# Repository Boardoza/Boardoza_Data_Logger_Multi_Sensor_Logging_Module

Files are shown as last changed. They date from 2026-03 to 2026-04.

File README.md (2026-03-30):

# Boardoza Data Logger Multi Sensor Logging Module

The **Boardoza Data Logger** is a powerful and compact data acquisition module designed for robust environmental, positional, and motion data logging. Built around the **ESP32-S module**, it combines high-performance on-board processing with wireless connectivity, making it ideal for both standalone and connected data logging applications.

By integrating multiple advanced sensors—including a 9-axis IMU, high-resolution barometric pressure sensor, and a precision GPS module—this board provides a complete solution for recording motion, altitude, orientation, and location data. With support for MicroSD storage and a wide input voltage range, the Boardoza Data Logger is well-suited for long-duration deployments in demanding environments such as aerospace experiments, environmental monitoring, robotics, and mobile data recording systems.

## [Click here to purchase!](https://www.ozdisan.com/p/arduino-sensorleri-ve-modulleri-613/boardoza-data-logger-1473935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)

| Front Side | Back Side |
|:---:|:---:|
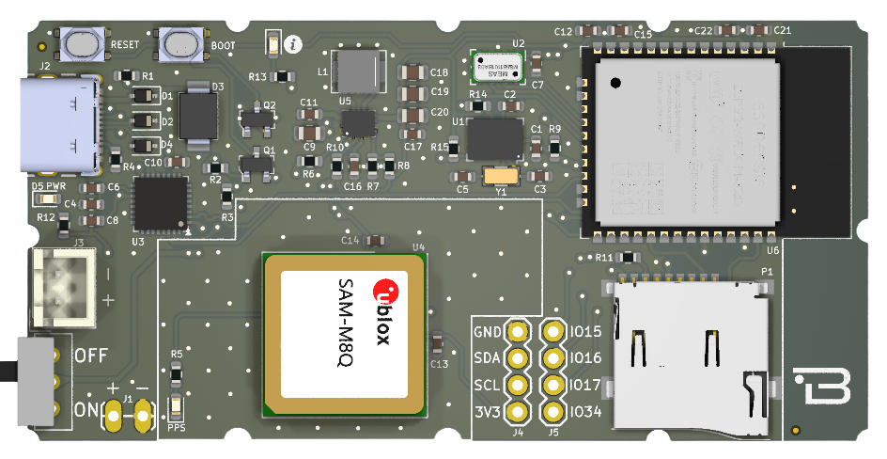
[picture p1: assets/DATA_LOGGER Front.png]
Data Logger Front
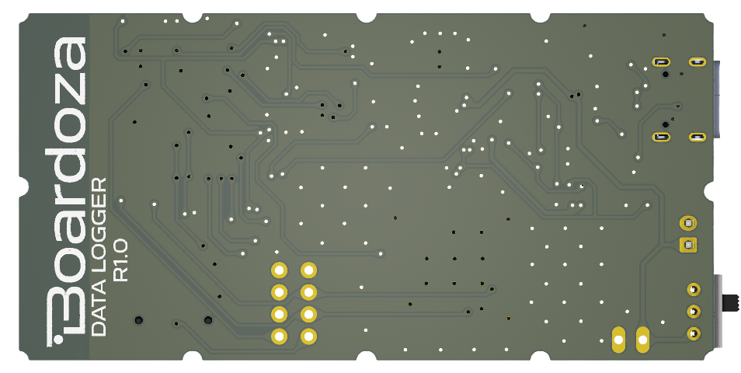
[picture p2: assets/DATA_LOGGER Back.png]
Data Logger Back
|  |  |

---

## Key Features

- **ESP32-S Module MCU:** Dual-core microcontroller with integrated Wi-Fi and Bluetooth for wireless data transmission.
- **Integrated 9-Axis IMU:** Combines accelerometer, gyroscope, and magnetometer for accurate motion and orientation tracking.
- **High-Resolution Barometric Sensor:** Enables precise pressure and altitude measurements.
- **Onboard GPS Module:** Provides reliable global positioning, speed, and navigation data.
- **MicroSD Card Support:** Allows long-term local data logging without external connectivity.
- **Wide Input Voltage Range:** Supports flexible power sources through an onboard buck-boost regulator.
- **External Expansion Pins:** Accessible I²C and GPIO pins for additional sensors and peripherals.
- **Designed for Harsh Environments:** Suitable for mobile, outdoor, and experimental applications.

---

## Technical Specifications

**Model:** Data Logger  
**Manufacturer:** Boardoza  
**MCU:** ESP32-S Module  
**Wireless Connectivity:** Wi-Fi (802.11 b/g/n/d/e/i/k/r), Bluetooth v4.2 BR/EDR and BLE    
**IMU Sensor:** BNO055 (9-axis: accelerometer, gyroscope, magnetometer, temperature)  
**Pressure and Temperature Sensor:** MS5611-01BA03  
**GPS Module:** u-blox SAM-M8Q  
**Input Voltage:** 3 V – 16 V  
**Voltage Regulation:** Onboard buck-boost regulator  
**Data Storage:** MicroSD Card  
**External Interfaces:** I²C, GPIO  
**Measured Data:** Acceleration, angular velocity, magnetic field, pressure, altitude, temperature, location, speed, timestamp     
**Operating Temperature:** -40 °C to +85 °C  
**Board Dimensions:** 40 mm × 80 mm

---

## Board Pinout

### **( J1 ) Power Connector**

| Pin Number | Pin Name | Description |
| --- | --- | --- |
| 1 | + | Power Input |
| 2 | - | Ground |

### **( J2 ) Power Connector**

| Pin Number | Pin Name | Description |
| --- | --- | --- |
| 1 | + | Power Input |
| 2 | - | Ground |

### **( J4 ) I²C Connector**

| Pin Number | Pin Name | Description |
| --- | --- | --- |
| 1 | 3V3 | 3.3V Output |
| 2 | SCL | I²C Serial Clock |
| 3 | SDA | I²C Serial Data |
| 4 | GND | Ground |

### **( J5 ) GPIO Connector**

| Pin Number | Pin Name | Description |
| --- | --- | --- |
| 1 | IO34 | ESP32 GPIO34 |
| 2 | IO17 | ESP32 GPIO17 |
| 3 | IO16 | ESP32 GPIO16 |
| 4 | IO15 | ESP32 GPIO15 |

---

## Sample Flight Data

Example altitude profile recorded during an amateur rocket flight:

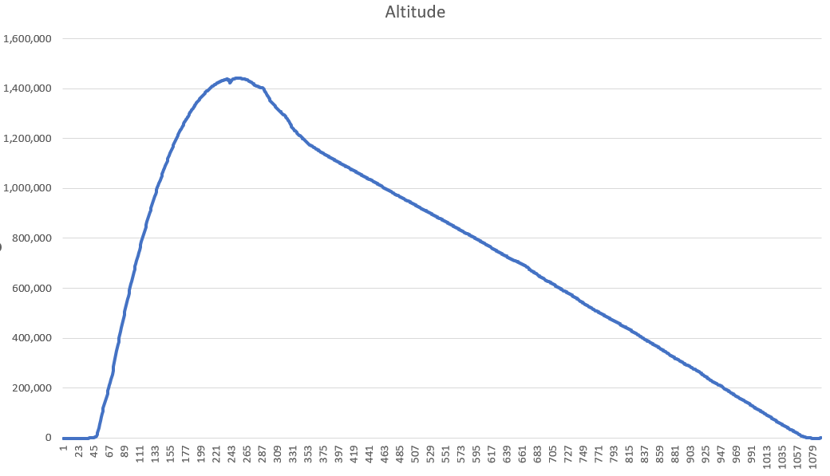
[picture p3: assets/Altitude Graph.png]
Altitude Graph


- Maximum altitude ~1,440 meters  
- Smooth ascent profile followed by controlled descent  
- Data logged using onboard MicroSD  

**Raw data file:**  
[Flight1.csv](./assets/_Flight1.csv)

**Simulation video:**  
[Data Logger Simulation.mp4](./assets/Data%20Logger%20Simulation.mp4)

---

## Board Dimensions

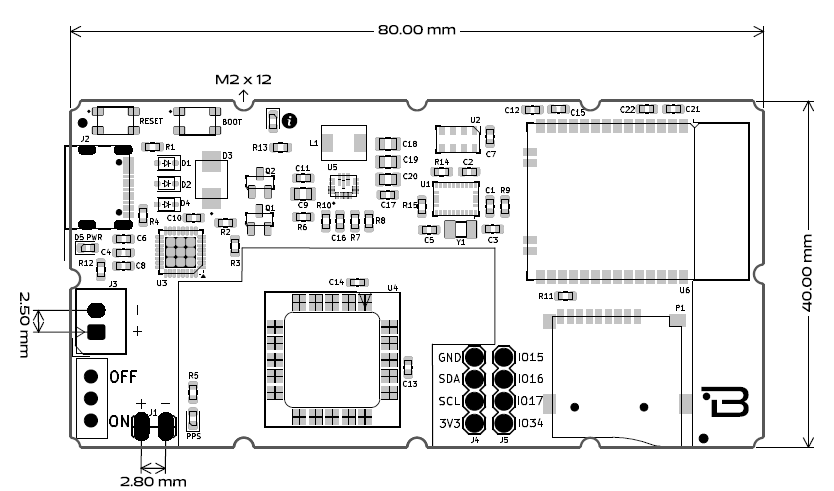
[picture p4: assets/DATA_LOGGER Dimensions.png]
Board Dimensions


---

## Step Files

[Boardoza Data Logger.step](./assets/DATA_LOGGER%20Step.step)

---

## Datasheets

- [BNO055 Datasheet](./assets/BNO055%20Datasheet.pdf)   
- [MS5611-01BA03 Datasheet](./assets/MS5611-01BA03%20Datasheet.pdf)  
- [SAM-M8Q Datasheet](./assets/SAM_M8Q%20Datasheet.pdf)  
- [TPS63070 Datasheet](./assets/TPS63070%20Datasheet.pdf)    

---

## Version History

- V1.0.0 – Initial Release

---

## Support

- If you have any questions or need support, please contact **support@boardoza.com**

---

## **License**

This repository contains both hardware and software components:

### **Hardware Design**

[][cc-by-sa]

All hardware design files are licensed under [Creative Commons Attribution-ShareAlike 4.0 International License][cc-by-sa].

[cc-by-sa]: http://creativecommons.org/licenses/by-sa/4.0/
[cc-by-sa-shield]: https://img.shields.io/badge/License-CC%20BY--SA%204.0-lightgrey.svg

### **Software/Firmware**

[][bsd]

All software and firmware are licensed under [BSD 3-Clause License][bsd].

[bsd]: https://opensource.org/licenses/BSD-3-Clause
[bsd-shield]: https://img.shields.io/badge/License-BSD%203--Clause-blue.svg

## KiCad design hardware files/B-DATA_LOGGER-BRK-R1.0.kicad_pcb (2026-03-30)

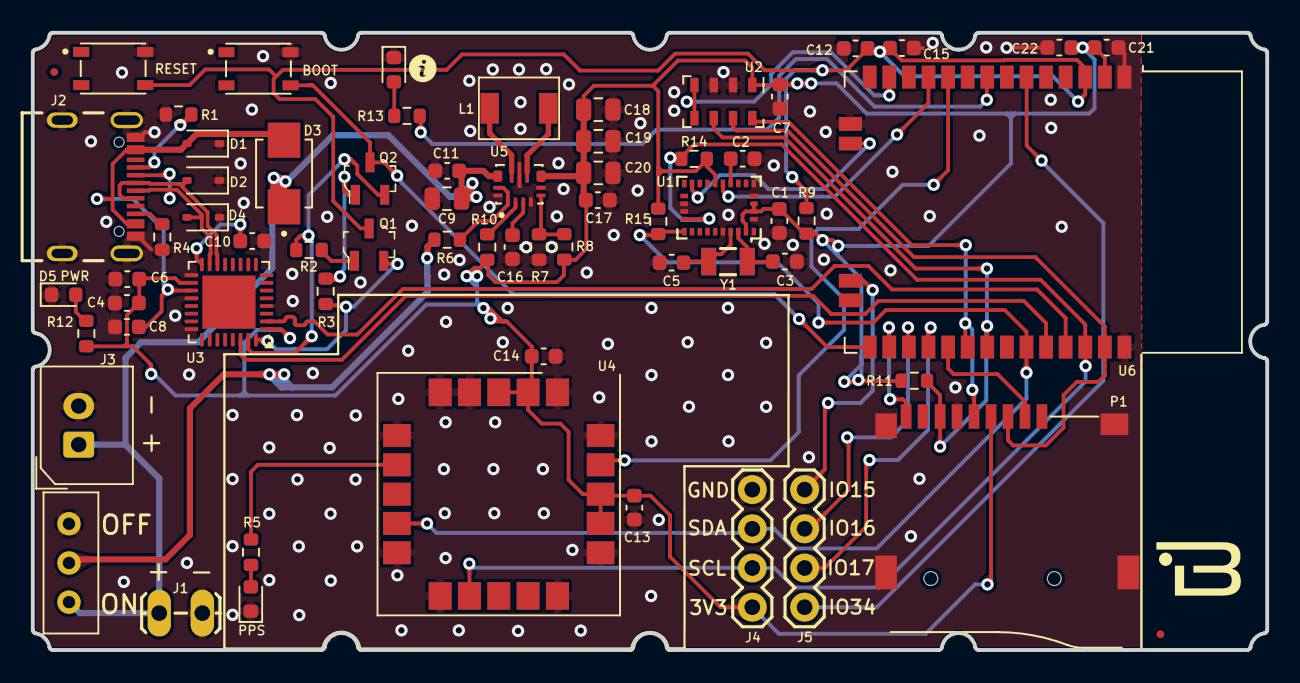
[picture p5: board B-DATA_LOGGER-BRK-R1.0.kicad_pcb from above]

Board: 2 copper layers, 80.0 x 40.0 mm, 63 parts (0 on the bottom side), 47 nets.

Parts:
BOOT1: PTS810_SJM_250_SMTR_LFS; SW_PTS810_SJM_250_SMTR_LFS
C1, C4, C6, C7, C8, C12, C13, C14, C15, C16, C22: 100nF; C_0603_1608Metric
C2, C10: 1uF; C_0603_1608Metric
C3, C5: 22pF; C_0603_1608Metric
C9, C18, C19, C20: 22uF; C_0805_2012Metric
C11, C17: 10uF; C_0603_1608Metric
C21: 22uF; C_0603_1608Metric
D1, D2, D4: SD05_SOD323; D_SOD-323
D3: SS24; DIOM5336X265N
D5: LED POWER RED; LED_0603_1608Metric
D6: LED BLUE; LED_0603_1608Metric
J1: Power pin; 1X02_LOCK_LONGPADS
J2: USB4105-GF-A; GCT_USB4105-GF-A
J3: 2317-02; 2317-02S_1x02_P2.50mm_Vertical
J4, J5: CONN_04; 1X04
L1: SMPI04020-1R5M; SMPI04020
P1: L-KLS1-TF-003-H1.85-R; SUNTECH_ST-TF-003A
PPS: LED GREEN; LED_0603_1608Metric
Q1, Q2: S8050; SOT-23-3
R1, R4: 5.1K; R_0603_1608Metric
R2, R3, R6, R9, R11, R14, R15: 10K; R_0603_1608Metric
R5, R12, R13: 1K; R_0603_1608Metric
R7: 150K; R_0603_1608Metric
R8: 470K; R_0603_1608Metric
R10: 100K; R_0603_1608Metric
RESET1: PTS810_SJM_250_SMTR_LFS; SW_PTS810_SJM_250_SMTR_LFS
S1: switch; K3-1260D
U1: BNO055; LGA-28_5.2x3.8mm_BNO0055
U2: MS5611-01BA; LGA-8_3x5mm_P1.25mm
U3: CY7C65213A-32LTXI; QFN-32-1EP_5x5mm_P0.5mm_EP3.45x3.45mm
U4: ublox_SAM-M8Q
U5: TPS630702RNMR; TPS63070RNMT
U6: ESP32-S; ESP32-WROOM-32D
Y1: CRYSTAL-32.768KHZSMD-3.2X1.5; CRYSTAL-SMD-3.2X1.5MM

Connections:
+3V3: C1.1, C4.1, C6.1, C7.1, C13.1, C14.1, C17.1, C18.1, C19.1, C20.1, C21.1, C22.1, J4.1, P1.4 (VDD), R8.2, R9.2, R10.1, R11.1, R12.1, R14.2, R15.2, U1.3 (VDD), U1.4 (BOOT_LOAD), U1.11 (RESET), U1.28 (VDDIO), U2.1 (VDD), U3.1 (VCCIO), U3.18 (~RESET), U4.2 (VCC_IO), U4.3 (V_BCKP), U4.17 (VCC), U4.18 (~RESET), U5.7_8 (VOUT), U6.2 (VDD)
+5V: C8.1, D1.2 (A2), D3.A, J2.A4_B9 (VBUS), J2.B4_A9 (VBUS), U3.19 (VCC)
+5VA: C9.1, C11.1, D3.C, J1.1, J3.1 (Pin_2), S1.3 (S), U5.12_13 (VIN)
BL_IND: U1.10 (BL_IND), U6.11 (IO26)
BNO_INT: U1.14 (INT), U6.16 (IO13)
D+: D2.2 (A2), J2.A6 (DP1), J2.B6 (DP2), U3.14 (USBDP)
D-: D4.2 (A2), J2.A7 (DN1), J2.B7 (DN2), U3.15 (USBDM)
DTR: Q2.2 (E), R2.2, U3.31 (DTR)
EN: C12.2, C15.1, Q1.3 (C), R9.1, RESET1.4, U6.3 (EN)
GND: BOOT1.2, C1.2, C2.2, C3.1, C4.2, C5.1, C6.2, C7.2, C8.2, C9.2, C10.2, C11.2, C12.1, C13.2, C14.2, C15.2, C16.2, C17.2, C18.2, C19.2, C20.2, C21.2, C22.2, D1.1 (A1), D2.1 (A1), D4.1 (A1), D5.1 (K), D6.1 (K), J1.2, J2.A1_B12 (GND), J2.B1_A12 (GND), J2.S1 (SHELL_GND), J2.S2 (SHELL_GND), J2.S3 (SHELL_GND), J2.S4 (SHELL_GND), J3.2 (Pin_1), J4.4, P1.6 (VSS), P1.G1 (GND), P1.G2 (GND), P1.G3 (GND), P1.G4 (GND), PPS.1 (K), R1.1, R4.1, R7.1, RESET1.2, S1.1 (O), U1.2 (GND), U1.5 (PS1), U1.6 (PS0), U1.17 (COM3), U1.18 (COM2), U1.25 (GNDIO), U2.2 (PS), U2.3 (GND), U3.4 (GND), U3.17 (GND), U3.20 (GND), U3.24 (AGND), U4.1 (GND), U4.4 (GND), U4.5 (GND), U4.6 (GND), U4.10 (GND), U4.11 (GND), U4.15 (GND), U4.16 (GND), U4.20 (GND), U5.4 (GND), U5.6 (FB2), U5.10 (PGND), U5.15 (VSEL), U6.1 (GND), U6.15 (GND), U6.38 (GND)
GPS_INT: U4.19 (EXTINT), U6.10 (IO25)
IO0: BOOT1.4, Q2.3 (C), U6.25 (IO0)
IO15: J5.1, U6.23 (IO15)
IO16: J5.2, U6.27 (IO16)
IO17: J5.3, U6.28 (IO17)
IO34: J5.4, U6.6 (IO34)
LED_INFO: R13.1, U6.8 (IO32)
MISO: P1.7 (DAT0), R11.2, U2.6 (SDO), U6.31 (IO19)
MOSI: P1.3 (CMD), U2.7 (SDI/SDA), U6.37 (IO23)
MS5611_CS: U2.4 (CSB), U2.5 (CSB), U6.13 (IO14)
unnamed: D5.2 (A), R12.2
unnamed: D6.2 (A), R13.2
unnamed: J2.A5 (CC1), R1.2
unnamed: J2.B5 (CC2), R4.2
unnamed: PPS.2 (A), R5.2
unnamed: Q1.1 (B), R2.1
unnamed: Q2.1 (B), R3.1
unnamed: R6.1, S1.2
unnamed: C2.1, U1.9 (CAP)
unnamed: C3.2, U1.27 (XIN32), Y1.P$1 (1)
unnamed: C5.2, U1.26 (XOUT32), Y1.P$2 (2)
unnamed: C10.1, U3.16 (VCCD)
unnamed: R5.1, U4.7 (TIMEPULSE)
unnamed: R6.2, U5.1 (PS/SYNC), U5.14 (EN)
unnamed: R7.2, R8.1, U5.5 (FB)
unnamed: L1.2, U5.11 (L1)
unnamed: L1.1, U5.9 (L2)
unnamed: R10.2, U5.2 (PG)
unnamed: C16.1, U5.3 (VAUX)
RTS: Q1.2 (E), R3.2, U3.32 (RTS)
RXD: U3.2 (RXD), U6.35 (TXD0/IO1)
SCK: P1.5 (CLK), U2.8 (SCLK), U6.30 (IO18)
SCL: J4.2, R14.1, U1.19 (COM1), U4.12 (SCL), U6.36 (IO22)
SDA: J4.3, R15.1, U1.20 (COM0), U4.9 (SDA), U6.33 (IO21)
SD_CS: P1.2 (DAT3), U6.29 (IO5)
SD_INSERT: P1.9 (CD), U6.26 (IO4)
TXD: U3.30 (TXD), U6.34 (RXD0/IO3)

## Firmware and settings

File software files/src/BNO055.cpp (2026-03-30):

#include "BNO055.h"
#include <SoftwareSerial.h>

SoftwareSerial mySerial(21, 22);

#define I2C
//#define UART

/**
 * @brief Constructor for BNO055 class.
 * 
 * Initializes the BNO055 object with the sensor's I2C address.
 * 
 */
BNO055::BNO055() {
    address = 0x28; // BNO055 sensor's I2C address
}

/**
 * @brief Initializes the BNO055 sensor.
 * 
 * This function initializes the BNO055 sensor by setting the necessary configurations and modes.
 * 
 * @return True if the sensor is successfully initialized, false otherwise.
 */
bool BNO055::begin() {
    #ifdef I2C
    Wire.begin();
    setPage(0x00);
    writeByte(0x3D, 0x00);
    delay(50);
    setPowerMode(PowerMode::POWERMODE_NORMAL);
    delay(10);
    setOperationMode(OperationMode::OPERATION_MODE_CONFIG);
    delay(50);
    return isReady();
    #endif

    #ifdef UART
    mySerial.begin(115200);
    setPage(0x00);
    writeByte(0x3D, 0x00);
    delay(30);
    setPowerMode(PowerMode::POWERMODE_NORMAL);
    delay(20);
    setOperationMode(OperationMode::OPERATION_MODE_CONFIG);
    delay(30);
    return isReady();
    #endif
}

/**
 * @brief Resets the BNO055 sensor.
 * 
 * This function performs a reset on the BNO055 sensor by triggering a reset sequence.
 * 
 */
void BNO055::reset() {
    setPage(0x00);
    writeByte(SYS_TRIGGER, 0x20);    
    delay(500);
    writeByte(SYS_TRIGGER, 0x00);
    delay(50);
}

/**
 * @brief Checks if the BNO055 sensor is ready.
 * 
 * This function checks the self-test result register to determine if the sensor is ready for operation.
 * 
 * @return True if the sensor is ready, false otherwise.
 */
bool BNO055::isReady() {
    setPage(0x00);
    uint8_t selfTest = readByte(SELFTEST_RESULT);

    return (selfTest & 0x0F);
}

/**
 * @brief Sets the power mode of the BNO055 sensor.
 * 
 * This function sets the power mode of the BNO055 sensor to the specified mode.
 * 
 * @param powermode The power mode to set (NORMAL, LOWPOWER, SUSPEND).
 */
void BNO055::setPowerMode(PowerMode powermode) {
    setPage(0x00);
    writeByte(PWR_MODE, powermode);
}

/**
 * @brief Sets the operation mode of the BNO055 sensor.
 * 
 * This function sets the operation mode of the BNO055 sensor to the specified mode.
 * 
 * @param mode The operation mode to set (CONFIG, ACCONLY, MAGONLY, GYRONLY, etc.).
 */
void BNO055::setOperationMode(OperationMode mode) {
    setPage(0x00);
    writeByte(OPR_MODE, mode);
}

/**
 * @brief Gets the current operation mode of the BNO055 sensor.
 * 
 * This function reads the operation mode register of the BNO055 sensor to get the current operation mode.
 * 
 * @return The current operation mode of the sensor (CONFIG, ACCONLY, MAGONLY, GYRONLY, etc.).
 */
OperationMode BNO055::getMode() {
    setPage(0x00);
    return (OperationMode)readByte(OPR_MODE);
}

/**
 * @brief Sets the page ID of the BNO055 sensor.
 * 
 * This function sets the page ID of the BNO055 sensor to the specified page.
 * 
 * @param page The page ID to set.
 */
void BNO055::setPage(uint8_t page) {
    writeByte(PAGE_ID, page);
}

/**
 * @brief Gets the current page ID of the BNO055 sensor.
 * 
 * This function reads the page ID register of the BNO055 sensor to get the current page ID.
 * 
 * @return The current page ID of the sensor.
 */
void BNO055::getPage() {
    readByte(PAGE_ID);
}

/**
 * @brief Resets the interrupt of the BNO055 sensor.
 * 
 * This function resets the interrupt of the BNO055 sensor by writing a specific value to the SYS_TRIGGER register. 
 */
void BNO055::interruptReset() {
    writeByte(SYS_TRIGGER, 0x40);
}

/**
 * @brief Sets the interrupt mask of the BNO055 sensor.
 * 
 * This function sets the interrupt mask of the BNO055 sensor by writing a specific value to the INT_MSK register.
 * 
 * @param mask The mask value to set for interrupts.
 */
void BNO055::interruptMask(uint8_t mask) {
    setPage(0x01);
    writeByte(INT_MSK, mask);
}

/**
 * @brief Enables specific interrupts on the BNO055 sensor.
 * 
 * This function enables specific interrupts on the BNO055 sensor by writing a specific value to the INT_EN register.
 * 
 * @param regVal The value to enable specific interrupts.
 */
void BNO055::interruptEnable(uint8_t regVal) {
    setPage(0x01);
    writeByte(INT_EN, regVal);
}

/**
 * @brief Disables all interrupts on the BNO055 sensor.
 * 
 * This function disables all interrupts on the BNO055 sensor by writing 0x00 to the INT_EN register.
 */
void BNO055::interruptDisable() {
    setPage(0x01);
    writeByte(INT_EN, 0x00);
}

/**
 * @brief Sets the accelerometer activity detection threshold on the BNO055 sensor.
 * 
 * This function sets the accelerometer activity detection threshold on the BNO055 sensor by writing a specific value to the ACC_AM_THRES register.
 * 
 * @param threshold The threshold value for accelerometer activity detection.
 */
void BNO055::accAMThresh(uint8_t threshold) {
    setPage(0x01);
    writeByte(ACC_AM_THRES, threshold);
}

/**
 * @brief Sets the accelerometer interrupt settings on the BNO055 sensor.
 * 
 * This function sets the accelerometer interrupt settings on the BNO055 sensor by writing specific values to the ACC_INT_SETTINGS register.
 * 
 * @param hgAxis The axis for high-g interrupt (X_AXIS, Y_AXIS, Z_AXIS).
 * @param motionAxis The axis for motion interrupt (X_AXIS, Y_AXIS, Z_AXIS).
 * @param duration The duration value for the interrupt.
 */
void BNO055::accIntSettings(uint8_t hgAxis, uint8_t motionAxis, uint8_t duration) {
    setPage(0x01);
    writeByte(ACC_INT_SETTINGS, hgAxis << 5| motionAxis << 2| duration);
}

/**
 * @brief Sets the duration for high-g acceleration interrupt on the BNO055 sensor.
 * 
 * This function sets the duration for high-g acceleration interrupt on the BNO055 sensor by writing a specific value to the ACC_HG_DURATION register.
 * 
 * @param hgDuration The duration value for high-g acceleration interrupt.
 */
void BNO055::accHGSettings(uint8_t hgDuration) {
    setPage(0x01);
    writeByte(ACC_HG_DURATION, hgDuration);
}

/**
 * @brief Sets the threshold for high-g acceleration interrupt on the BNO055 sensor.
 * 
 * This function sets the threshold for high-g acceleration interrupt on the BNO055 sensor by writing a specific value to the ACC_HG_THRES register.
 * 
 * @param threshold The threshold value for high-g acceleration interrupt.
 */
void BNO055::accHGThresh(uint8_t threshold) {
    setPage(0x01);
    writeByte(ACC_HG_THRES, threshold);
}

/**
 * @brief Sets the threshold for no-motion interrupt on the BNO055 sensor.
 * 
 * This function sets the threshold for no-motion interrupt on the BNO055 sensor by writing a specific value to the ACC_NM_THRES register.
 * 
 * @param threshold The threshold value for no-motion interrupt.
 */
void BNO055::accNMThresh(uint8_t threshold) {
    setPage(0x01);
    writeByte(ACC_NM_THRES, threshold);
}
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

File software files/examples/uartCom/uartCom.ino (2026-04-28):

#include <Wire.h>
#include <SoftwareSerial.h>

// BNO055 UART communication pins
#define PS0_PIN  5
#define PS1_PIN  18
#define RX_PIN   21
#define TX_PIN   22

SoftwareSerial mySerial(RX_PIN, TX_PIN);  // RX, TX pins are defined

uint8_t writeByte(uint8_t reg, uint8_t value) {

    uint8_t buffer[5];
    buffer[0] = 0xAA;    // Start byte
    buffer[1] = 0x00;    // Write command (0x00)
    buffer[2] = reg;     // Register address
    buffer[3] = 0x01;    // Length of data to write (1 byte)
    buffer[4] = value;   // Data to write

    for (int i = 0; i < 5; i++) {
        mySerial.write(buffer[i]);
    }

    unsigned long startMillis = millis();
    while (mySerial.available() < 1) {  // Wait until response arrives
        if (millis() - startMillis > 1000) {  // 1 second timeout
            Serial.println("Write response not received.");
            return 0;  // Return error since no response received
        }
    }

    uint8_t response = mySerial.read();
    if (response == 0xEE) {
        Serial.println("Write operation successful.");
    } else {
        Serial.print("Unexpected response: 0x");
        Serial.println(response, HEX);  // Print the unexpected response
    }

    return value;  // Return the written value upon successful write
}

uint8_t readChipID() {
  uint8_t value = 0;
  uint8_t response = 0;
  uint8_t buffer[6];
  uint8_t count=0;

  buffer[0] = 0xAA;    // Start byte
  buffer[1] = 0x01;    // Read command (0x01)
  buffer[2] = 0x3D;    // CHIP_ID register address (e.g., could be 0x00)
  buffer[3] = 0x01;    // Read 1 byte of data
  buffer[4] = 0xBB;
  buffer[5] = 0x01;

  // Send command via UART
  for (int i = 0; i < 4; i++) {
    mySerial.write(buffer[i]);
  }

  // Wait for response (up to 1 second)
  unsigned long startMillis = millis();
  while (mySerial.available() < 1) {
    if (millis() - startMillis > 1000) {
      Serial.println("Response not received.");
      return 0;
    }
  }

  response=mySerial.read();
  if (response==0xBB);
    {
      count=mySerial.read();
      for(int i = 0; i < count; i++){ 
        value=mySerial.read(); 
      }
    }
  if (response==0xEE)
    {
    Serial.print(mySerial.read(), HEX);    
    }  

  return value; // Return the read CHIP_ID value
}

void setup() {
  pinMode(PS0_PIN, OUTPUT);
  pinMode(PS1_PIN, OUTPUT);

  digitalWrite(PS0_PIN, LOW);   // PS0 = LOW
  digitalWrite(PS1_PIN, HIGH);  // PS1 = HIGH

  Serial.begin(115200);         // Initialize hardware Serial for debugging
  mySerial.begin(115200);

}

void loop() {
  //writeByte(0x3D, 0x01);
  //delay(30);
  uint8_t chipID = readChipID();

  // Print the CHIP_ID value
  Serial.print("CHIP_ID: 0x");
  Serial.println(chipID, HEX);
  //Serial.println(bnoSensor.readByte(0x00));
  delay(250);
}

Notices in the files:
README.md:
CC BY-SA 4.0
